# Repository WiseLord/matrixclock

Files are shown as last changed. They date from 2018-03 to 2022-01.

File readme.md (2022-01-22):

# Matrixclock

This project is a simple LED matrix clock. It can use either MAX7219 as LED drivers (one IC per matrix) either HT1632 LED driver. It's possible to use 3 or 4 matrixes, but recent code is more suitable for second option.

There is a [video](https://youtu.be/mCT93ut2W2s) on Youtube about this.

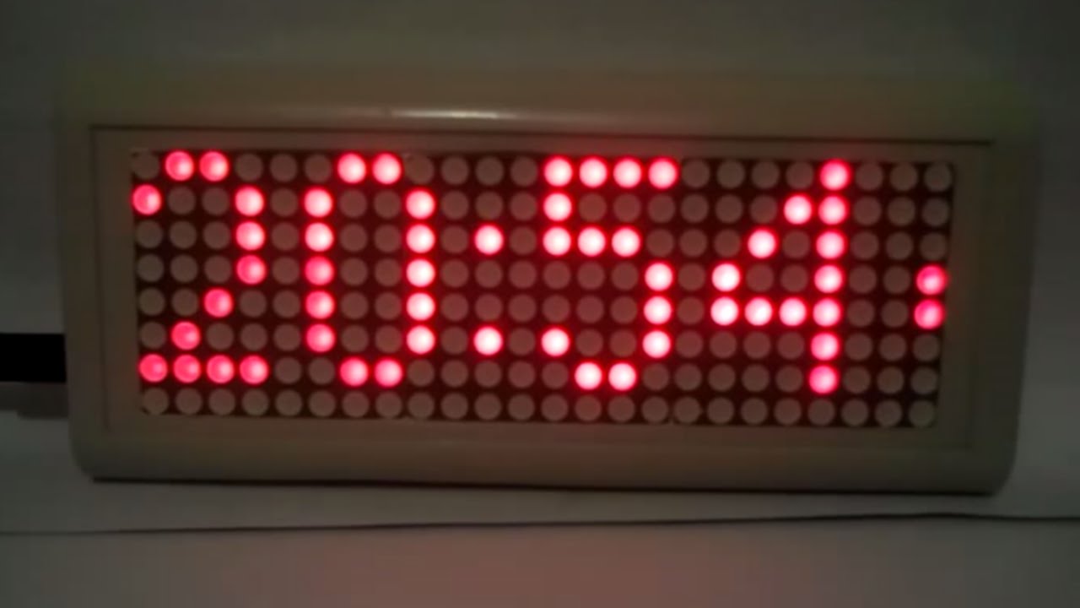
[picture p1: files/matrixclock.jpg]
Matrixclock


# Main features:

* RTC DS1307 support (DS3231 also works)
* One alarm which can be enabled for any day of week
* Active beeper is used for alarm and signals
* Temperature measurement with DS18B20 sensors
* Pressure/temperature measurement with BMP180 sensor
* Humidity/temperature measurement with DHT22 sensor
* Scrolling date and sensors data strings
* Reducing brigtness in darkness

# Supported LED drivers:

* MAX7219 (one per LED matrix). Pinout and schematic are [here](files/schematic.png)
* HT1632 (one for 4 matrixes). Pinout for _JY-MCU 3208CLOCK PRO_ module

# Matrixclock EEPROM editor

While project uses various parameters from EEPROM memory special desktop application to edit eeprom matrixclock_xx.bin was designed. It allows to load, modify and save eeprom binary file in easy way.

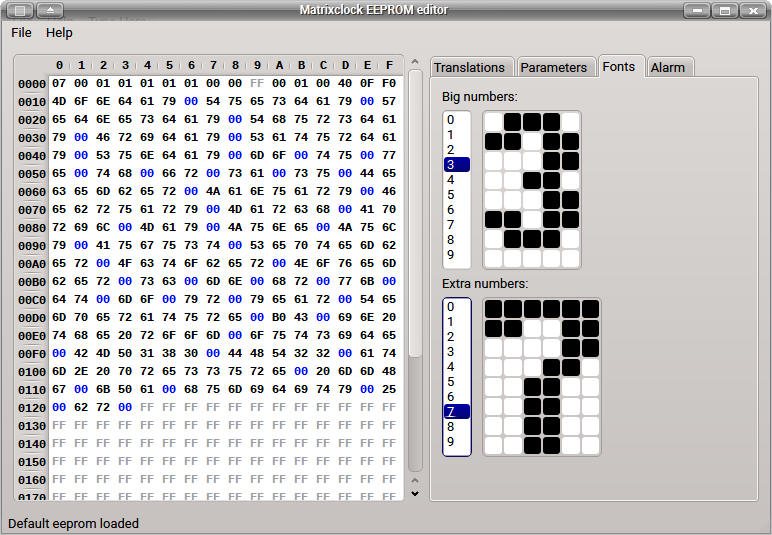
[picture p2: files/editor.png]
EEPROM editor


Matrixclock editor is written on Qt5 and it's sources are availiable [here](editor).

# Useful links:

* [Article about the project](http://radiokot.ru/circuit/digital/home/206) (in Russian)
* [Forum thread](http://radiokot.ru/forum/viewtopic.php?t=112934) (in Russian)

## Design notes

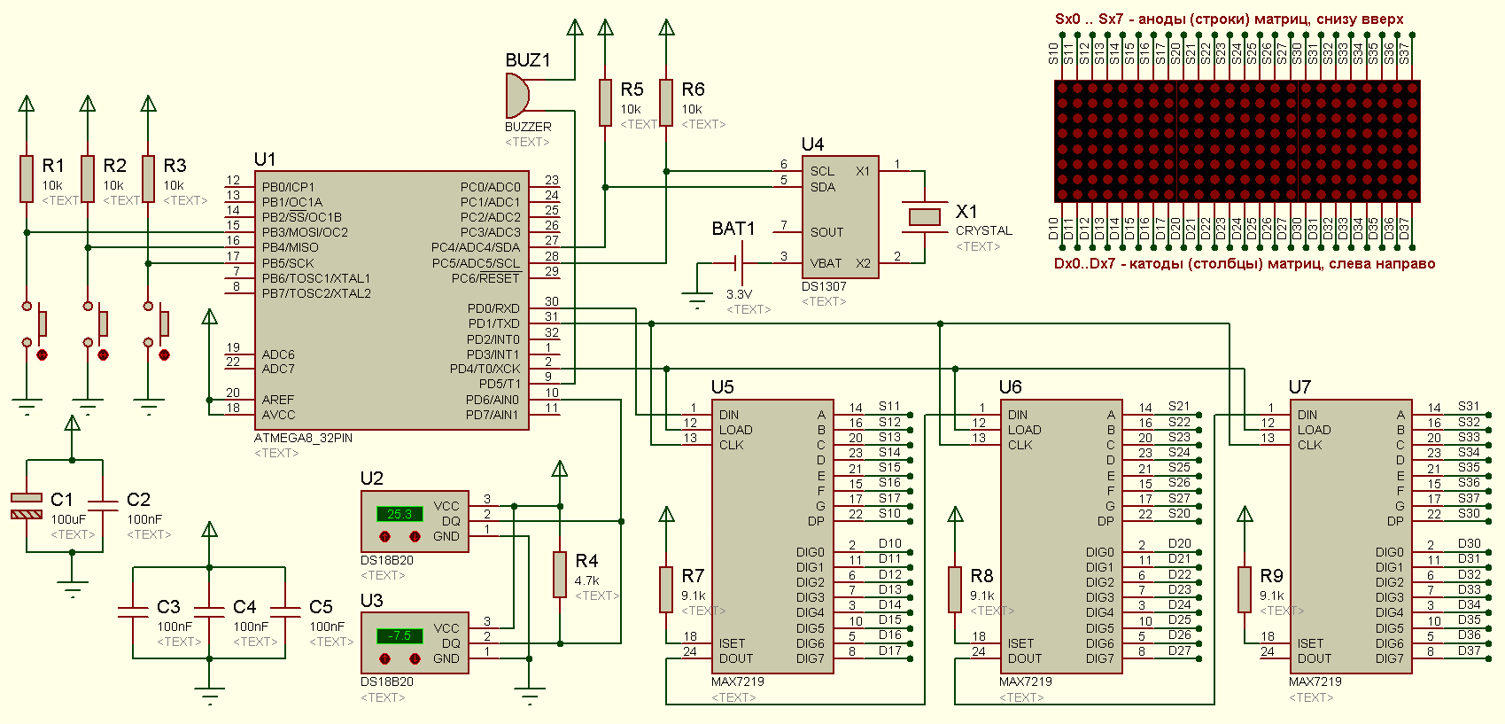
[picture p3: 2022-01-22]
files/schematic.png

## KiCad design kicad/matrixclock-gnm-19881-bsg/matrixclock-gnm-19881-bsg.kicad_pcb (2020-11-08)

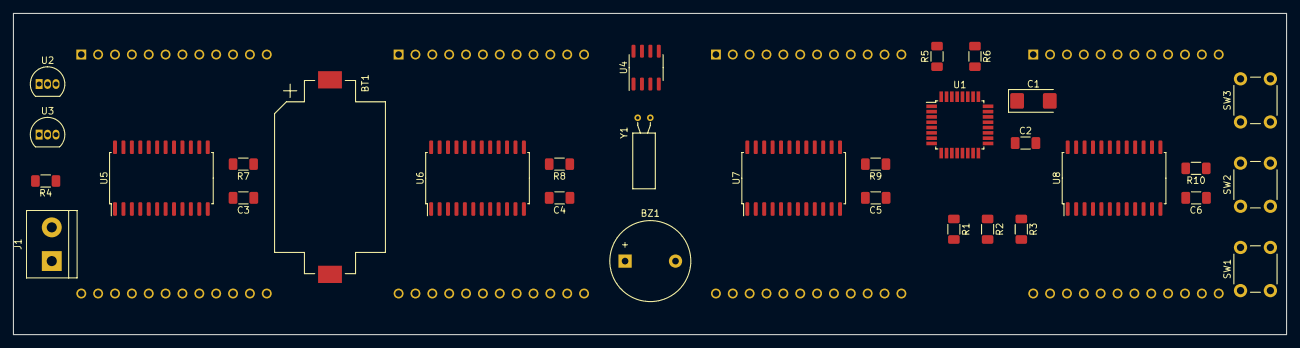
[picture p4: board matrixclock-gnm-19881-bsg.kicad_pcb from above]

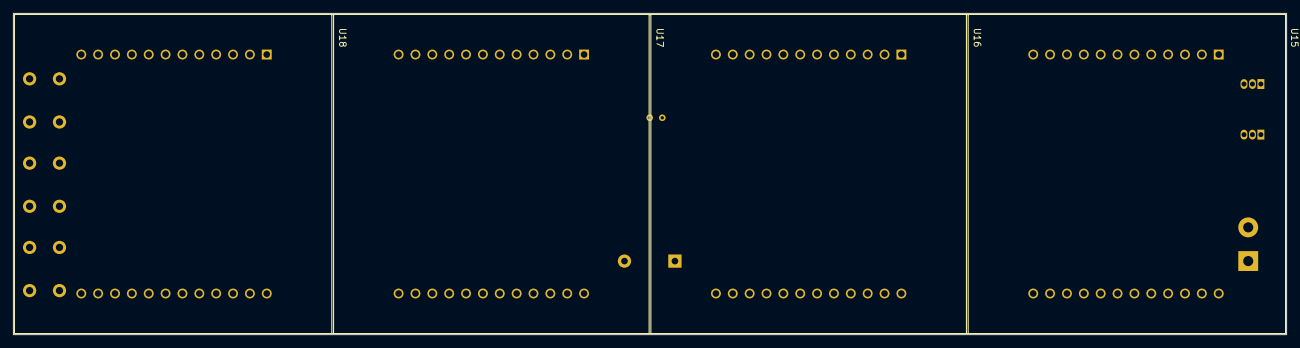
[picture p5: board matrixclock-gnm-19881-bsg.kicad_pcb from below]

Board: 2 copper layers, 191.8 x 48.4 mm, 35 parts (4 on the bottom side), 86 nets, no tracks yet.

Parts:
BT1: Li_3.3V; BatteryHolder_Keystone_1060_1x2032
BZ1: Buzzer; Buzzer_12x9.5RM7.6
C1: 100.0; CP_EIA-6032-28_Kemet-C
C2, C3, C4, C5, C6: 0.1; C_1206_3216Metric_Pad1.33x1.80mm_HandSolder
J1: PWR; TerminalBlock_bornier-2_P5.08mm
R1, R2, R3, R7, R8, R9, R10: 10k; R_1206_3216Metric_Pad1.30x1.75mm_HandSolder
R4, R5, R6: 4k7; R_1206_3216Metric_Pad1.30x1.75mm_HandSolder
SW1: MENU; SW_PUSH_6mm
SW2: INC; SW_PUSH_6mm
SW3: DEC; SW_PUSH_6mm
U1: ATmega328P-AU; TQFP-32_7x7mm_P0.8mm
U2, U3: DS18B20; TO-92_Inline
U4: DS1307Z+; SOIC-8_3.9x4.9mm_P1.27mm
U5, U6, U7, U8: MAX7219; SOIC-24W_7.5x15.4mm_P1.27mm
U15, U16, U17, U18: GNM-19881-BSG
Y1: 32768; Crystal_C38-LF_D3.0mm_L8.0mm_Horizontal

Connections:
+5VD: BZ1.1, C1.1, C2.1, C3.1, C4.1, C5.1, C6.1, J1.2, R1.1, R2.1, R3.1, R4.1, R5.1, R6.1, R7.1, R8.1, R9.1, R10.1, U1.4, U1.6, U1.18, U1.20, U2.3, U3.3, U4.8, U5.19, U6.19, U7.19, U8.19
/BTN1: R1.2, SW1.1, U1.15
/BTN2: R2.2, SW2.1, U1.16
/BTN3: R3.2, SW3.1, U1.17
/BUZZ: BZ1.2, U1.9
/CLK: U1.31, U5.13, U6.13, U7.13, U8.13
/DIN: U1.30, U5.1
/DQ: R4.2, U1.10, U2.2, U3.2
/LOAD: U1.2, U5.12, U6.12, U7.12, U8.12
/SCL: R6.2, U1.28, U4.6
/SDA: R5.2, U1.27, U4.5
/mxblock1/D0: U5.2, U15.24
/mxblock1/D1: U5.11, U15.3
/mxblock1/D2: U5.6, U15.21
/mxblock1/D3: U5.7, U15.6
/mxblock1/D4: U5.3, U15.18
/mxblock1/D5: U5.10, U15.9
/mxblock1/D6: U5.5, U15.15
/mxblock1/D7: U5.8, U15.12
/mxblock1/S0: U5.22, U15.10
/mxblock1/S1: U5.14, U15.13
/mxblock1/S2: U5.16, U15.7
/mxblock1/S3: U5.20, U15.16
/mxblock1/S4: U5.23, U15.4
/mxblock1/S5: U5.21, U15.19
/mxblock1/S6: U5.15, U15.1
/mxblock1/S7: U5.17, U15.22
/mxblock2/D0: U6.2, U16.24
/mxblock2/D1: U6.11, U16.3
/mxblock2/D2: U6.6, U16.21
/mxblock2/D3: U6.7, U16.6
/mxblock2/D4: U6.3, U16.18
/mxblock2/D5: U6.10, U16.9
/mxblock2/D6: U6.5, U16.15
/mxblock2/D7: U6.8, U16.12
/mxblock2/DIN: U5.24, U6.1
/mxblock2/S0: U6.22, U16.10
/mxblock2/S1: U6.14, U16.13
/mxblock2/S2: U6.16, U16.7
/mxblock2/S3: U6.20, U16.16
/mxblock2/S4: U6.23, U16.4
/mxblock2/S5: U6.21, U16.19
/mxblock2/S6: U6.15, U16.1
/mxblock2/S7: U6.17, U16.22
/mxblock3/D0: U7.2, U17.24
/mxblock3/D1: U7.11, U17.3
/mxblock3/D2: U7.6, U17.21
/mxblock3/D3: U7.7, U17.6
/mxblock3/D4: U7.3, U17.18
/mxblock3/D5: U7.10, U17.9
/mxblock3/D6: U7.5, U17.15
/mxblock3/D7: U7.8, U17.12
/mxblock3/DIN: U6.24, U7.1
/mxblock3/S0: U7.22, U17.10
/mxblock3/S1: U7.14, U17.13
/mxblock3/S2: U7.16, U17.7
/mxblock3/S3: U7.20, U17.16
/mxblock3/S4: U7.23, U17.4
/mxblock3/S5: U7.21, U17.19
/mxblock3/S6: U7.15, U17.1
/mxblock3/S7: U7.17, U17.22
/mxblock4/D0: U8.2, U18.24
/mxblock4/D1: U8.11, U18.3
/mxblock4/D2: U8.6, U18.21
/mxblock4/D3: U8.7, U18.6
/mxblock4/D4: U8.3, U18.18
/mxblock4/D5: U8.10, U18.9
/mxblock4/D6: U8.5, U18.15
/mxblock4/D7: U8.8, U18.12
/mxblock4/DIN: U7.24, U8.1
/mxblock4/S0: U8.22, U18.10
/mxblock4/S1: U8.14, U18.13
/mxblock4/S2: U8.16, U18.7
/mxblock4/S3: U8.20, U18.16
/mxblock4/S4: U8.23, U18.4
/mxblock4/S5: U8.21, U18.19
/mxblock4/S6: U8.15, U18.1
/mxblock4/S7: U8.17, U18.22
GNDD: BT1.2, C1.2, C2.2, C3.2, C4.2, C5.2, C6.2, J1.1, SW1.2, SW2.2, SW3.2, U1.3, U1.5, U1.21, U2.1, U3.1, U4.4, U5.4, U5.9, U6.4, U6.9, U7.4, U7.9, U8.4, U8.9
unnamed: BT1.1, U4.3
unnamed: R7.2, U5.18
unnamed: R8.2, U6.18
unnamed: R9.2, U7.18
unnamed: R10.2, U8.18
unnamed: U4.1, Y1.1
unnamed: U4.2, Y1.2

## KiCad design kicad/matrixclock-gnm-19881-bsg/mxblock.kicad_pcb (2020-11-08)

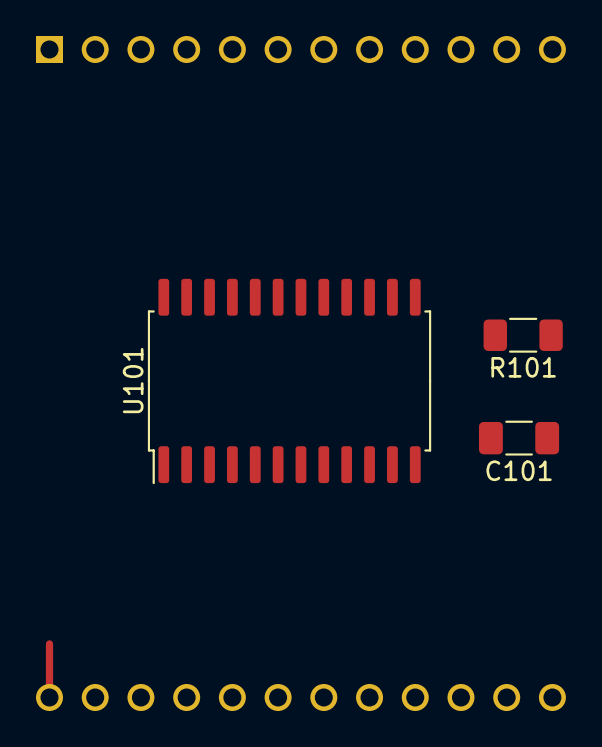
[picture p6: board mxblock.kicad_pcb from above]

Board: 2 copper layers, 4 parts (1 on the bottom side), 19 nets.

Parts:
C101: 0.1; C_1206_3216Metric_Pad1.33x1.80mm_HandSolder
R101: 10k; R_1206_3216Metric_Pad1.30x1.75mm_HandSolder
U101: MAX7219; SOIC-24W_7.5x15.4mm_P1.27mm
U102: GNM-19881-BSG

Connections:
+5VD: C101.1, R101.1, U101.19
/D0: U101.2, U102.24
/D1: U101.11, U102.3
/D2: U101.6, U102.21
/D3: U101.7, U102.6
/D4: U101.3, U102.18
/D5: U101.10, U102.9
/D6: U101.5, U102.15
/D7: U101.8, U102.12
/S0: U101.22, U102.10
/S1: U101.14, U102.13
/S2: U101.16, U102.7
/S3: U101.20, U102.16
/S4: U101.23, U102.4
/S5: U101.21, U102.19
/S6: U101.15, U102.1
/S7: U101.17, U102.22
GNDD: C101.2, U101.4, U101.9
unnamed: R101.2, U101.18

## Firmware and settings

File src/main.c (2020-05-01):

#include <avr/interrupt.h>
#include <util/delay.h>

#include "matrix.h"
#include "fonts.h"
#include "mtimer.h"
#include "display.h"
#include "ds18x20.h"
#include "rtc.h"
#include "alarm.h"
#include "bmp180.h"
#include "dht22.h"
#include "eeprom.h"

void hwInit(void)
{
    _delay_ms(250);

    ds18x20SearchDevices();
    bmp180Init();
    dht22Init();

    displayInit();

    mTimerInit();

    matrixScrollAndADCInit();

    alarmInit();

    rtc.etm = RTC_NOEDIT;

    sei();

    return;
}

int main(void)
{
    uint8_t cmd;
    uint8_t dispMode = MODE_MAIN;

    hwInit();

    showTimeMasked();

    ds18x20Process();
    sensTimer = TEMP_MEASURE_TIME;

    while (1) {
        // Update sensors with SENSOR_POLL_INTERVAL period
        if (!sensTimer) {
            sensTimer = SENSOR_POLL_INTERVAL;
            ds18x20Process();
            if (bmp180HaveSensor())
                bmp180Convert();
            dht22Read();
        }

        // Check alarm
        checkAlarm();

        // Update brightness only when not in brightness setup
        if (dispMode != MODE_BRIGHTNESS)
            calcBrightness();

        // Get command from buttons
        cmd = getBtnCmd();

        // Beep on button pressed
        if (cmd != BTN_STATE_0) {
            if (cmd < BTN_0_LONG)
                startBeeper(BEEP_SHORT);
            else
                startBeeper(BEEP_LONG);
        }

        // Stop scrolling on any button pressed
        if (cmd != BTN_STATE_0)
            matrixHwScroll(MATRIX_SCROLL_STOP);

        int8_t direction = PARAM_UP;
        displaySetDirection(direction);

        // Handle command
        switch (cmd) {
        case BTN_0:
            switch (dispMode) {
            case MODE_EDIT_TIME:
                rtcNextEditParam();
                break;
            case MODE_EDIT_ALARM:
                alarmNextEditParam();
                break;
            }
            break;
        case BTN_1:
        case BTN_2:
            direction = cmd == BTN_1 ? PARAM_UP : PARAM_DOWN;
            displaySetDirection(direction);
            switch (dispMode) {
            case MODE_MAIN:
                startScroll(cmd == BTN_1 ? SCROLL_DATE : SCROLL_TEMP);
                break;
            case MODE_EDIT_TIME:
                displayChangeTime();
                break;
            case MODE_EDIT_ALARM:
                displayChangeAlarm();
                break;
            case MODE_BRIGHTNESS:
                changeBrightness(direction);
                break;
            case MODE_CORRECTION:
                changeCorrection(direction);
                break;
            case MODE_TEST:
                displayChangeRotate(direction);
                break;
            }
            break;
        case BTN_0_LONG:
            if (dispMode == MODE_MAIN) {
                dispMode = MODE_EDIT_TIME;
                rtcNextEditParam();
            } else {
                rtc.etm = RTC_NOEDIT;
                alarmSave();
                alarm.eam = ALARM_NOEDIT;
                dispMode = MODE_MAIN;
                showTimeMasked();
            }
            break;
        case BTN_1_LONG:
            if (dispMode == MODE_MAIN) {
                dispMode = MODE_EDIT_ALARM;
                alarmNextEditParam();
            }
            break;
        case BTN_2_LONG:
            if (dispMode == MODE_MAIN || dispMode == MODE_CORRECTION) {
                dispMode = MODE_BRIGHTNESS;
                showBrightness(1);
            } else if (dispMode == MODE_BRIGHTNESS) {
                dispMode = MODE_CORRECTION;
                showCorrection(1);
            }
            break;
        case BTN_0_LONG | BTN_1_LONG:
            displaySwitchHourZero();
            dispMode = MODE_MAIN;
            showTimeMasked();
            break;
        case BTN_1_LONG | BTN_2_LONG:
            displaySwitchBigNum();
            dispMode = MODE_MAIN;
            showTimeMasked();
            break;
        case BTN_0_LONG | BTN_2_LONG:
            displaySwitchHourSignal();
            dispMode = MODE_MAIN;
            showTimeMasked();
            break;
        case BTN_0_LONG | BTN_1_LONG | BTN_2_LONG:
            dispMode = MODE_TEST;
            break;
        }

        // Show things
        switch (dispMode) {
        case MODE_MAIN:
            showMainScreen();
            break;
        case MODE_EDIT_TIME:
            showTimeEdit();
            break;
        case MODE_EDIT_ALARM:
            showAlarmEdit();
            break;
        case MODE_BRIGHTNESS:
            showBrightness(0);
            break;
        case MODE_CORRECTION:
            showCorrection(0);
            break;
        case MODE_TEST:
            showTest();
            break;
        }
    }

    return 0;
}

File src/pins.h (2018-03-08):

#ifndef PINS_H
#define PINS_H

#include <avr/io.h>

#define CONCAT(x,y)         x ## y

#define DDR(x)              CONCAT(DDR,x)
#define PORT(x)             CONCAT(PORT,x)
#define PIN(x)              CONCAT(PIN,x)

#define OUT(x)              (DDR(x) |= x ## _LINE)
#define IN(x)               (DDR(x) &= ~x ## _LINE)
#define SET(x)              (PORT(x) |= x ## _LINE)
#define CLR(x)              (PORT(x) &= ~x ## _LINE)
#define READ(x)             (PIN(x) & x ## _LINE)

#if !defined(_HT1632) && !defined(_MAX7219) && !defined(_MAX7219_X3)
#define _HT1632
#endif

#if defined(_HT1632)

#define ONE_WIRE            C
#define ONE_WIRE_LINE       (1<<1)

#define BEEPER              C
#define BEEPER_LINE         (1<<0)

#define BUTTON_1            D
#define BUTTON_1_LINE       (1<<7)
#define BUTTON_2            D
#define BUTTON_2_LINE       (1<<6)
#define BUTTON_3            D
#define BUTTON_3_LINE       (1<<5)

#define I2C_SCL             B
#define I2C_SCL_LINE        (1<<0)
#define I2C_SDA             B
#define I2C_SDA_LINE        (1<<2)

#define ADC_CHANNEL         7

#define DHT_DATA            D
#define DHT_DATA_LINE       (1<<3)

#else

#define ONE_WIRE            D
#define ONE_WIRE_LINE       (1<<6)

#define BEEPER              D
#define BEEPER_LINE         (1<<5)

#define BUTTON_1            B
#define BUTTON_2            B
#define BUTTON_3            B
#define BUTTON_1_LINE       (1<<3)
#define BUTTON_2_LINE       (1<<4)
#define BUTTON_3_LINE       (1<<5)

#define I2C_SCL             C
#define I2C_SCL_LINE        (1<<5)
#define I2C_SDA             C
#define I2C_SDA_LINE        (1<<4)

#define ADC_CHANNEL         0

#define DHT_DATA            D
#define DHT_DATA_LINE       (1<<3)

#endif

#define HT1632_CS           B
#define HT1632_CS_LINE      (1<<3)
#define HT1632_WR           B
#define HT1632_WR_LINE      (1<<4)
#define HT1632_DATA         B
#define HT1632_DATA_LINE    (1<<5)

#define MAX7219_LOAD        D
#define MAX7219_LOAD_LINE   (1<<4)
#define MAX7219_CLK         D
#define MAX7219_CLK_LINE    (1<<1)
#define MAX7219_DIN         D
#define MAX7219_DIN_LINE    (1<<0)

#endif // PINS_H

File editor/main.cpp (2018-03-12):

#include "mainwindow.h"
#include "defines.h"

#include <QApplication>
#include <QTranslator>
#include <QSettings>

int main(int argc, char *argv[])
{
    QCoreApplication::setOrganizationName(ORGANIZATION_NAME);
    QCoreApplication::setOrganizationDomain(ORGANIZATION_DOMAIN);
    QCoreApplication::setApplicationName(APPLICATION_NAME);

    QApplication a(argc, argv);
    MainWindow w;
    w.show();

    return a.exec();
}

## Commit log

2014-08-24 Added support of DS18X20 temperature sensors.
2014-08-30 Switch to pgmspace strings.
2014-08-30 Hardware scroll based on timers instead of delays.
2014-08-30 Buttons polling added.
2014-08-30 Buttons handling in main mode.
2015-02-03 Change code for several MAX7219 connected to chain. Control with 3 lines only.
2015-02-03 Optimize buttons behaviour.
2015-02-04 Fix year string output.
    [display.c]
2015-04-30 HT1632 led driver support.
2015-05-01 Add software I2C pins definitions
2015-05-01 Switch to software I2C.
2015-05-03 Code refactoring. Fix scroll bug.
    [matrix.c]
2015-05-05 Set BODLEVEL to 4V.
2015-05-06 Switch to main screen when changing font.
2015-05-06 Fix entering edit time/alarm mode.
    [display.c]
2015-05-07 Switch to CP1251 encoding.
2015-05-07 Code optimizations and fixes.
    [display.c]
2015-05-07 Fix 0 hour brightness level corruption op power on.
    [display.c]
2015-05-28 Switch hour leading zero by 1-2 long button press.
2015-05-30 Optimizations in DS18x20 driver.
2015-05-30 Optimizations and refacroting in software I2C.
2015-05-30 Added measuring ADC level (future brightness).
2015-06-19 Added some more strings to eeprom for future pressure/humidity measurements.
2015-06-19 Show temperature label.
2015-06-20 Optimize DS18x20 driver.
2015-06-21 Fix show time on power on.
    [display.c, main.c]
2015-06-21 Fix space near year.
    [display.c]
2015-06-21 Barometric sensor bmp180 support.
2015-06-21 Some fixes and improvements.
    [display.c, main.c, matrix.h]
2015-06-21 Fix brightness auto control.
    [display.c]
2015-06-22 Fix output hours with hourZero enabled.
    [matrix.c]
2015-06-26 Fast temperature measure on start.
2015-06-26 Fix brightness when no photoresistor installed.
    [display.c]
2015-07-09 Fix pinout for MAX7219MOD.
    [pins.h]
2015-07-09 Optimize timers and ADC.
2015-07-14 Small optimize by size MAX7219 drivers.
2015-07-14 Small optimize by size HT1632 drivers.
2015-07-14 Return output "Temperature" word.
2015-07-14 Smooth brightness control and filter noise.
    [display.c]
2015-07-14 Ouptupt of sensor data from DHT22/BMP180 can be disabled.
2015-07-14 Fix build for three MAX7219 option.
    [pins.h]
2015-07-16 Optimize timers.
2015-07-16 Optimize buttons polling code. Buttons can be used only on the same port.
2015-07-18 Change button 1 behaviour.
2015-07-26 Optimize buttons long press behaviour.
2015-07-27 Fix minutes label when tuning alarm.
    [display.c]
2015-09-01 Switch raw weekday type from int8_t to uint8_t
2015-09-11 Ability to switch off every hour signal
2015-09-12 Fix alarm and hourclock indication.
    [display.c]
2015-09-12 Fix font switch on MOD2_X3
    [display.c]
2015-09-12 Better colon and alarm indicator switch look-n-feel
2015-09-30 Reset seconds to 0 when edit them. Fix freeze time during edit.
    [rtc.c]
2015-09-30 Sync DS18x20 driver with ampcontrol project to save some RAM
2015-11-08 Fix clearing screen before scroll and zeroing first column
    [display.c, matrix.c]
2015-11-25 Add some useful files
    [matrixclock_max7219mod_atmega328.hex.dsn, matrixclock_max7219mod_atmega8.hex.dsn]
2016-02-06 Fix weekday calculating on change date
    [rtc.c]
2016-04-02 Remove screen rotate with 1-2-3 buttons feature
2016-08-08 Update proteus project
    [matrixclock_max7219mod_atmega8.hex.dsn]
2016-08-08 Refactoring some timers
2016-08-08 Refactored alarm timer
2016-08-09 Refactoring access to framebuffer
2016-08-10 Update Proteus project files
    [matrixclock_max7219_atmega328.hex.dsn, matrixclock_max7219_atmega8.hex.dsn, matrixclock_max7219mod_atmega328.hex.dsn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]
2017-10-31 Fix Feb days calculation.
    [rtc.c]
2018-03-08 Fix build for MAX7219
    [pins.h]
2018-03-12 Do seconds correction once a week
    [display.c]
2018-03-12 Update binary files
    [matrixclock_max7219_atmega328.hex.dsn, matrixclock_max7219_atmega8.hex.dsn]
2018-03-12 editor: switch language on the fly
2020-11-08 Prepare KiCad project skeleton for GNM-19981-BSG
    [matrixclock-gnm-19881-bsg.kicad_pcb, matrixclock-gnm-19881-bsg.sch]
2020-11-08 Add schematic and basic PCB skeleton
    [matrixclock-gnm-19881-bsg.kicad_pcb, matrixclock-gnm-19881-bsg.sch, mxblock.kicad_pcb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]
